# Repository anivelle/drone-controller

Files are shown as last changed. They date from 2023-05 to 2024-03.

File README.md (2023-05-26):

# PID Drone Controller

This is my repository for the drone controller I am building using the Arduino
Nano 33 BLE. This is an exercise for me in working directly with the Arduino's
hardware peripherals, as well as learning about PID (I have never taken a
feedback control course).

I'll be using some sort of time of flight (TOF) sensor to give the drone the
ability to hover at a certain height, along with a 9-axis IMU (currently the
BNO055 because I have it) to keep the drone stabilized in the air. That is all
that is currently planned, but if I enjoy this enough I might try autonomous
movement.

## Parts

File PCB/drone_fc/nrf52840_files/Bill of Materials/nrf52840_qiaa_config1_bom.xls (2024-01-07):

Bill of material
Device: | nRF52840-QIAA
Title: | Reference Layout Config. 1: VBUS supply, LDO only, USB
Version: | 1.3
Designator | Value | Description | Assembly | Footprint Doc
C1, C2, C17, C18 | 12pF | Capacitor, NP0, ±2% |  | 0402
C3 | 0.8pF | Capacitor, NP0, ±10% |  | 0402
C4 | 0.5pF | Capacitor, NP0, ±10% |  | 0402
C5, C7, C8, C12 | 100nF | Capacitor, X7R, ±10% |  | 0402
C6, C20 | 4.7µF | Capacitor, X7R, ±10% |  | 0603
C9 | 820pF | Capacitor, NP0, ±5% | Not required for Fxx and later | 0402
C10, C13, C22 | N.C. | Not mounted | Not mounted | 0402
C11 | 100pF | Capacitor, NP0, ±5% |  | 0402
C14, C15 | 1.0µF | Capacitor, X7R, ±10% |  | 0603
C19 | 4.7µF | Capacitor, X7S, ±10% |  | 0603
L1 | 4.7nH | High frequency chip inductor ±5% |  | 0402
R1 | 2R2 | Resistor, ±1%, 0.063W |  | 0402
U1 | nRF52840-QIAA | Multi-protocol Bluetooth Low Energy, IEEE 802.15.4, ANT and 2.4GHz proprietary system-on-chip |  | AQFN-73
X1 | 32MHz | XTAL SMD 2016, 32MHz, Cl=8pF, Total Tol: ±40ppm |  | XTAL_2016
X2 | 32.768kHz | XTAL SMD 3215, 32.768kHz, Cl=9pF, Total Tol: ±50ppm |  | XTAL_3215

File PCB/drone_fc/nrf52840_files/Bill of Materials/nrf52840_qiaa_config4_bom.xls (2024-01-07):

Bill of material
Device: | nRF52840-QIAA
Title: | Reference Layout Config. 4: VDDH supply, DCDC, USB
Version: | 1.3
Designator | Value | Description | Assembly | Footprint Doc
C1, C2, C17, C18 | 12pF | Capacitor, NP0, ±2% |  | 0402
C3 | 0.8pF | Capacitor, NP0, ±10% |  | 0402
C4 | 0.5pF | Capacitor, NP0, ±10% |  | 0402
C5, C7, C8, C12 | 100nF | Capacitor, X7R, ±10% |  | 0402
C6, C20 | 4.7µF | Capacitor, X7R, ±10% |  | 0603
C9 | 820pF | Capacitor, NP0, ±5% | Not required for Fxx and later | 0402
C10, C13, C22 | N.C. | Not mounted | Not mounted | 0402
C11 | 100pF | Capacitor, NP0, ±5% |  | 0402
C14, C15 | 1.0µF | Capacitor, X7R, ±10% |  | 0603
C16 | 47nF | Capacitor, X7R, ±10% |  | 0402
C19, C21 | 4.7µF | Capacitor, X7S, ±10% |  | 0603
L1 | 4.7nH | High frequency chip inductor ±5% |  | 0402
L2 | 10µH | Chip inductor, IDC,min = 50 mA, ±20% |  | 0603
L3 | 15nH | High frequency chip inductor ±10% |  | 0402
L4 | 10µH | Chip inductor, IDC,min = 80 mA, ±20% |  | 0603
U1 | nRF52840-QIAA | Multi-protocol Bluetooth Low Energy, IEEE 802.15.4, ANT and 2.4GHz proprietary system-on-chip |  | AQFN-73
X1 | 32MHz | XTAL SMD 2016, 32MHz, Cl=8pF, Total Tol: ±40ppm |  | XTAL_2016
X2 | 32.768kHz | XTAL SMD 3215, 32.768kHz, Cl=9pF, Total Tol: ±50ppm |  | XTAL_3215

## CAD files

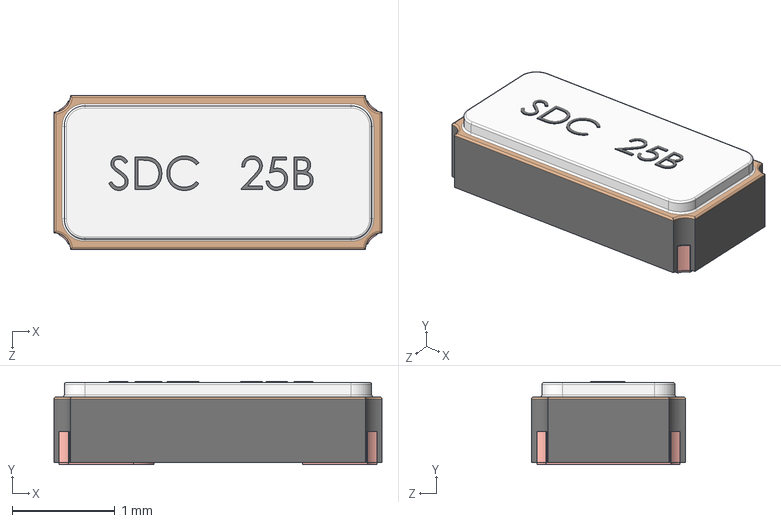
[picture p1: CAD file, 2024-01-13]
PCB/drone_fc/nrf52840_files/Altium Designer files/ALTIUM_EMBEDDED_MODELS/User Library-Siward_SX3215.step
3.20 x 0.81 x 1.50 mm

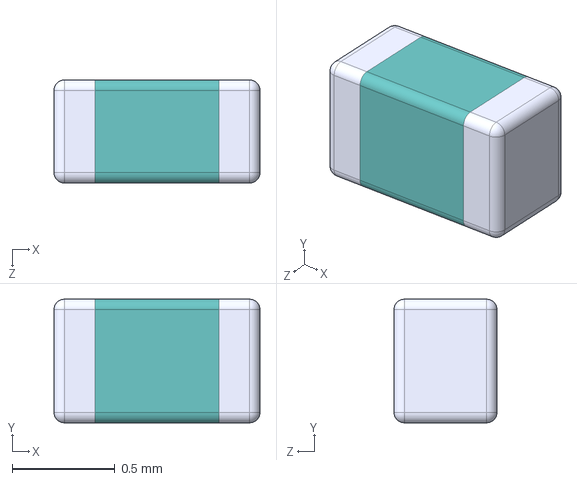
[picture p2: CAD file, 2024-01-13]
PCB/drone_fc/nrf52840_files/Altium Designer files/ALTIUM_EMBEDDED_MODELS/User Library-Chip Inductor 0402.step
1.00 x 0.6 x 0.5 mm

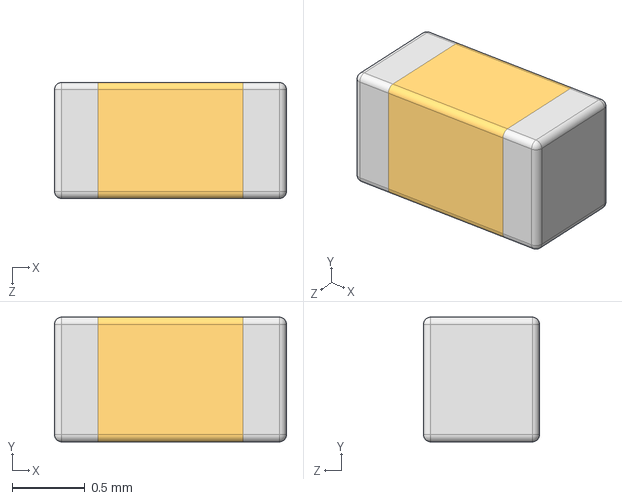
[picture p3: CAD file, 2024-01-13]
PCB/drone_fc/nrf52840_files/Altium Designer files/ALTIUM_EMBEDDED_MODELS/User Library-Chip Capacitor 0603.step
1.60 x 0.86 x 0.8 mm

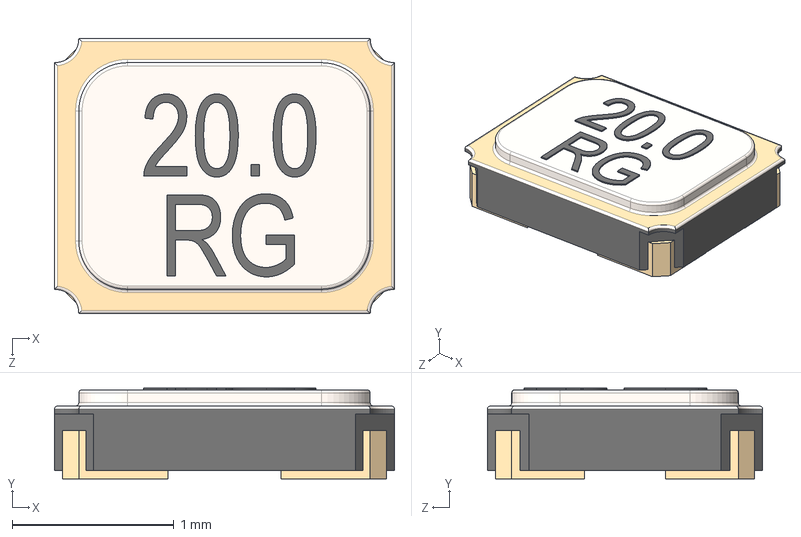
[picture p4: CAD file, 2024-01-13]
PCB/drone_fc/nrf52840_files/Altium Designer files/ALTIUM_EMBEDDED_MODELS/User Library-GeyerElectronics_KX5.step
2.10 x 0.56 x 1.70 mm

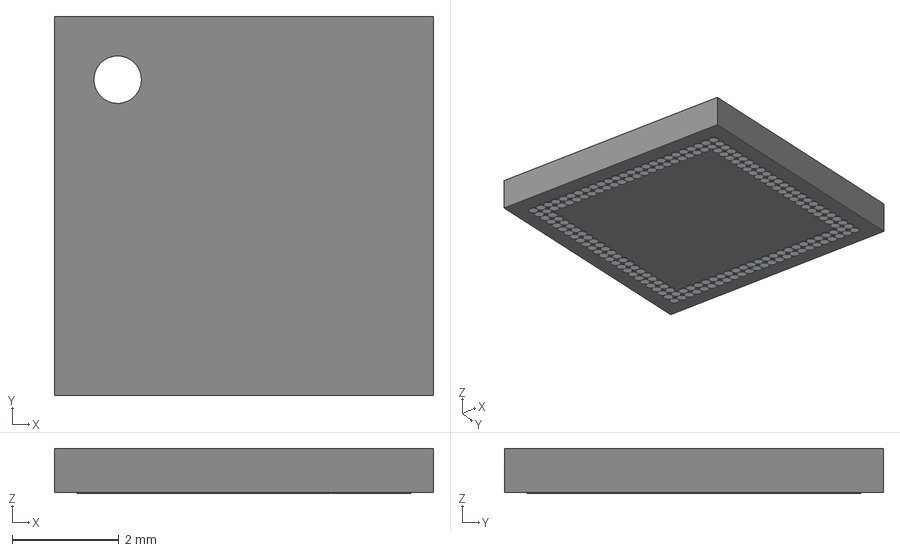
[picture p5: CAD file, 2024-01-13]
PCB/drone_fc/nrf52840_files/Altium Designer files/ALTIUM_EMBEDDED_MODELS/LGA88C25P25X25_700X700X85.step
7.10 x 7.10 x 0.85 mm
pinShape x 184

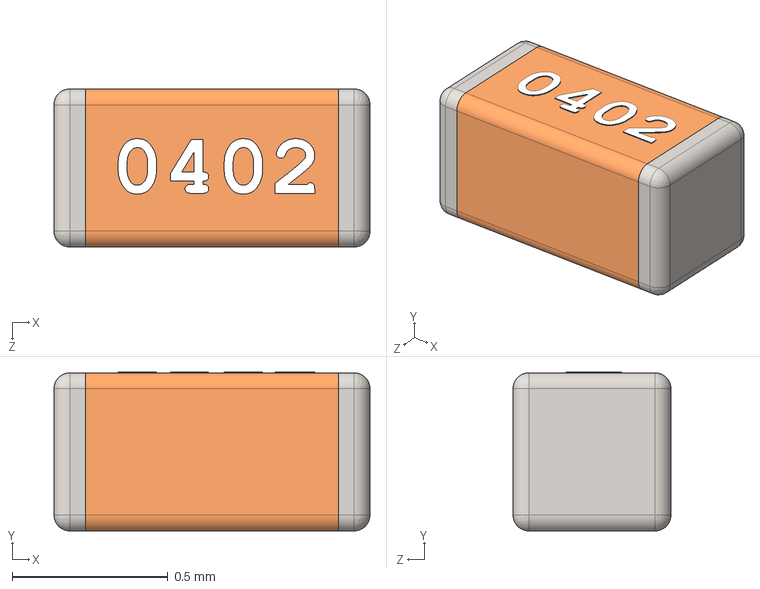
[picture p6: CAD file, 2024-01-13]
PCB/drone_fc/nrf52840_files/Altium Designer files/ALTIUM_EMBEDDED_MODELS/User Library-0402(1005M) Cap.step
1.02 x 0.511 x 0.508 mm

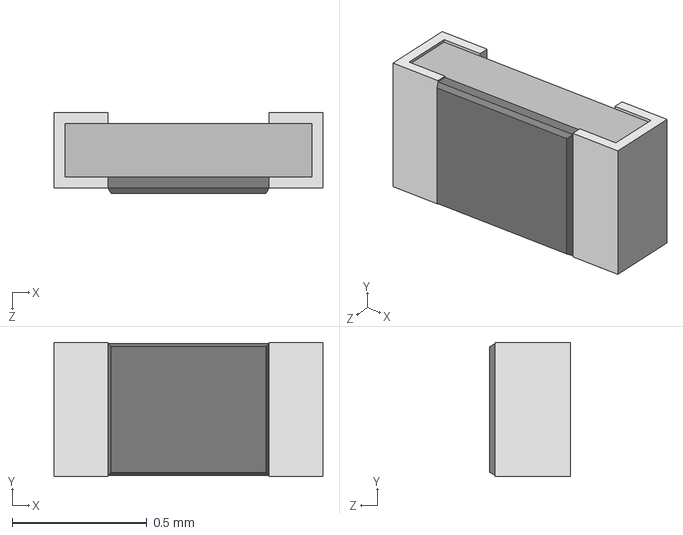
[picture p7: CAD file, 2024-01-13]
PCB/drone_fc/nrf52840_files/Altium Designer files/ALTIUM_EMBEDDED_MODELS/User Library-res0402-1.step
1.00 x 0.5 x 0.3 mm

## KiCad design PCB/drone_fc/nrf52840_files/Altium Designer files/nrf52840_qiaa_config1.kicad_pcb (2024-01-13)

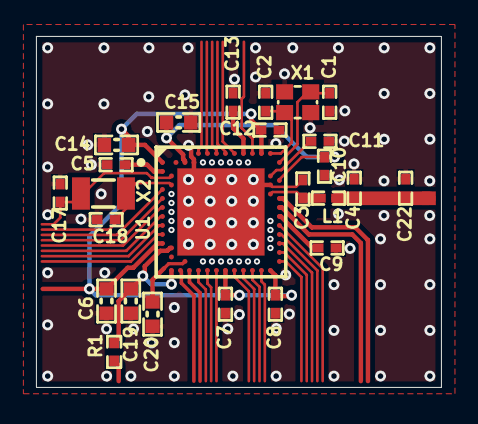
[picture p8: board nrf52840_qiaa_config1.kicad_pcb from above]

Board: 4 copper layers, 22.5 x 19.5 mm, 25 parts (0 on the bottom side), 15 nets.

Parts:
C1, C2: 12pF; CAPC1005X04L
C3: 0.8pF; CAPC1005X04L
C4: 0.5pF; _Applications_test_rsk_lib_RSK-ONLY_PcbLib_Passive.PcbLib_C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
C5, C7, C8: 100nF; CAPC1005X04L
C6, C19, C20: 4.7µF; _Applications_test_rsk_lib_RSK-ONLY_PcbLib_Passive.PcbLib_C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
C9: 820pF; CAPC1005X04L
C10, C13: N.C.; _Applications_test_rsk_lib_RSK-ONLY_PcbLib_Passive.PcbLib_C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
C11: 100pF; _Applications_test_rsk_lib_RSK-ONLY_PcbLib_Passive.PcbLib_C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
C12: 100nF; _Applications_test_rsk_lib_RSK-ONLY_PcbLib_Passive.PcbLib_C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
C14, C15: 1.0µF; _Applications_test_rsk_lib_RSK-ONLY_PcbLib_Passive.PcbLib_C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
C17, C18: 12pF; _Applications_test_rsk_lib_RSK-ONLY_PcbLib_Passive.PcbLib_C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
C22: N.C.; _Application_test_rsk_lib_RSK-ONLY_PcbLib_Passive.PcbLib_CA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
L1: 4.7nH; INDC1005X04L
R1: 2R2; _Applications_test_rsk_lib_RSK-ONLY_PcbLib_Passive.PcbLib_R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
U1: nRF52840-QIAA; _Applications_test_rsk_lib_RSK-ONLY_PcbLib_AQFN50P700X700X8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
X1: 32MHz; BT-XTAL_2016
X2: 32.768kHz; _Repositories_Applications_test_rsk_lib_RSK-ONLY_PcbLib_pcb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

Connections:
DEC1: C5.1, U1.C1
DEC3: C11.1, U1.D23
DEC4_6: C10.2, C15.2, U1.B5, U1.E24
GND: C1.2, C2.2, C3.1, C4.1, C5.2, C6.2, C7.2, C8.2, C9.2, C10.1, C11.2, C12.2, C13.2, C14.2, C15.1, C17.2, C18.2, C19.2, C20.2, C22.2, U1.74, U1.B7, U1.F23, X1.2, X1.4
NetC3_2: C3.2, L1.1, U1.H23
NetC9_1: C9.1, U1.N24
NetC13_1: C13.1, U1.A18
NetC20_1: C20.1, U1.AC5
P0.00/XL1: C17.1, U1.D2, X2.1
P0.01/XL2: C18.1, U1.F2, X2.2
RF: C4.2, C22.1, L1.2
VBUS_nRF: C19.1, R1.2, U1.AD2, U1.Y2
VDD_NRF: C6.1, C7.1, C8.1, C12.1, C14.1, U1.A22, U1.AD14, U1.AD23, U1.B1, U1.W1
XC1: C1.1, U1.B24, X1.1
XC2: C2.1, U1.A23, X1.3

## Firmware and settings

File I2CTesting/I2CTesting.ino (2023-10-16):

#include <stdint.h>
#include <stdio.h>
#include <Wire.h>
#include "BNO055.h"
#include "VL53L4CX.h"
#include "LowPowerTicker.h"

typedef enum State { CONFIGURING, CALIBRATING, FLYING } State_t;

BNO055 gyro(&Wire);
VL53L4CX distSensor(&Wire, A1);

int err;
int units;
uint8_t calibration;
State state;
State nextState;
uint8_t makeTransition = 0;
uint8_t calib_state = 0xFF;

mbed::LowPowerTicker ticker;

const char *titles[] = {"Heading", "Roll", "Pitch"};
volatile uint8_t drdy;
volatile uint8_t rrdy;
int angle[3];
volatile int temp;
uint8_t ready;
VL53L4CX_MultiRangingData_t ranging_data;
int status;

void timer_callback() {
    // if (NRF_TIMER3->EVENTS_COMPARE[0]) {
    drdy = 1;
    //   NRF_TIMER3->EVENTS_COMPARE[0] = 0;
    //   temp = NRF_TIMER3->EVENTS_COMPARE[0];
    //   temp;
    //}
}

void ready_callback() { rrdy = 1; }

void setup() {
    state = CONFIGURING;
    Serial.begin(115200);
    // Very important for serial to work properly (inside setup, at least)
    while (!Serial) {
    }
    Wire.begin();
    // Configuration stuff here
    delay(850); // Startup time for I2C? Not sure if necessary

    // Timer interrupt for the IMU (I still believe)
    // NRFX_IRQ_DISABLE(TIMER3_IRQn);
    // NRF_TIMER3->PRESCALER = PWM_PRESCALER_PRESCALER_DIV_32;
    // NRF_TIMER3->CC[0] = 5000;
    // NRF_TIMER3->BITMODE = TIMER_BITMODE_BITMODE_16Bit;
    // NRF_TIMER3->INTENSET |= TIMER_INTENSET_COMPARE0_Msk;
    // NRF_TIMER3->SHORTS = TIMER_SHORTS_COMPARE0_CLEAR_Msk;
    // NRFX_IRQ_PRIORITY_SET(TIMER3_IRQn, 7);
    // NRFX_IRQ_ENABLE(TIMER3_IRQn);
    drdy = 0;

    distSensor.begin();
    distSensor.VL53L4CX_Off();
    distSensor.InitSensor(0x12);
    attachInterrupt(A2, ready_callback, FALLING);
    status = distSensor.VL53L4CX_StartMeasurement();

    if (status) {
        Serial.println("Failed to init distSensor");
    }
    // Ends the config mode
    err = gyro.changeMode(NDOF);
    if (err != 0) {
        Serial.println("ERROR: Did not write properly");
        Serial.println(err);
    }
    err = gyro.readRegister(OPR_MODE);
    if (err != NDOF) {
        Serial.println("ERROR: Operation mode not set");
        Serial.println(err);
    } else {
        Serial.println("We're good");
    }

    ticker.attach(&timer_callback, 0.5f);
    units = gyro.readRegister(UNIT_SEL);
    Serial.println("Beginning Calibration");
    makeTransition = 1;
    nextState = CALIBRATING;
    // Serial.println(NRFX_IRQ_IS_ENABLED(TIMER3_IRQn));
}

void loop() {
    int numObjects;
    switch (state) {
    case CONFIGURING:
        break;
    case CALIBRATING:
        calibration = gyro.readRegister(CALIB_STAT);
        Serial.println(calibration, BIN);
        if ((calibration & calib_state) & (3 << 4)) {
            calib_state ^= (3 << 4);
            Serial.println("Gyro calibration done");
        }
        if ((calibration & calib_state) & (3 << 2)) {
            calib_state ^= (3 << 2);
            Serial.println("Accelerometer calibration done");
        }
        if ((calibration & calib_state) & 3) {
            calib_state ^= 3;
            Serial.println("Magnetometer calibration done");
        }
        if (calibration &
            (3 << 6) /*|| (~calib_state & 0b111111 == 0b111111)*/) {
            calib_state ^= (3 << 6);
            Serial.println("Done Calibrating");
            nextState = FLYING;
            makeTransition = true;
        }
        break;
    case FLYING:
        // status = distSensor.VL53L4CX_GetMeasurementDataReady(&ready);
      
        // Using this condition kinda invalidates the point of the hardware
        // interrupt (though frankly I'm only doing this to have a slower,
        // human-readable output). Thinking I might just use the hardware
        // interrupt as my entire data collection interrupt
        if (rrdy && drdy) {
            status = distSensor.VL53L4CX_GetMultiRangingData(&ranging_data);
            numObjects = ranging_data.NumberOfObjectsFound;
            Serial.print("Found ");
            Serial.print(numObjects);
            Serial.println(" Objects");
            for (int i = 0; i < numObjects; i++) {
                char buf[13];
                sprintf(buf, "Distance %d: ", i);
                Serial.print(buf);
                Serial.println(ranging_data.RangeData[i].RangeMilliMeter);
                Serial.println();
            }
            if (!status)
                distSensor.VL53L4CX_ClearInterruptAndStartMeasurement();
            for (int i = 0; i < 3; i++) {
                angle[i] = gyro.readEul((Axis)i);
                if (units & 4)
                    angle[i] /= 900;
                else
                    angle[i] /= 16;
                Serial.print(titles[i]);
                Serial.print(": ");
                Serial.println(angle[i]);
            }
            drdy = 0;
        }
        break;
    default:
        break;
    }
    if (makeTransition) {
        // Small things to do on exiting a state
        switch (state) {
        case CONFIGURING:
            if (nextState == FLYING)
                NRF_TIMER1->TASKS_START = 1;
            break;
        case CALIBRATING:
            NRF_TIMER1->TASKS_START = 1;
            NRF_TIMER1->TASKS_CLEAR = 1;
            break;
        case FLYING:
            NRF_TIMER1->TASKS_STOP = 1;
        }
        makeTransition = 0;
        state = nextState;
    }
}

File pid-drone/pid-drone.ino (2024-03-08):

#include <cstdio>
#include <stdint.h>
#include "mbed.h"
#include "VL53L4CX.h"
#include "PWM.h"
#include "DShot.h"
#include "Wire.h"
// Not using the BNO055 anymore
// #include "BNO055.h" 

#define TELEMETRY 0
#define POTENTIOMETER A0

uint16_t commands[4];
uint16_t throttle;

uint16_t seq[SEQ_SIZE];

VL53L4CX distanceSensor(&Wire, A1);
//BNO055 gyro(&Wire);

uint8_t dataReady;
int status;
uint16_t prevTime, curTime;

void setup() {
    // distanceSensor.VL53L4CX_WaitDeviceBooted();
    // distanceSensor.VL53L4CX_DataInit();
    Serial.begin(115200);
    // This causes the PWM output to wait until I open a serial monitor, 
    // which may or may not be desirable
    while (!Serial) {
        ;
    }
    Wire.begin();
    distanceSensor.begin();
    distanceSensor.VL53L4CX_Off();
    distanceSensor.InitSensor(0x12);

    distanceSensor.VL53L4CX_StartMeasurement();
    //gyro.writeRegister(OPR_MODE, AMG);
  
    commands[0] = 0;
    commands[1] = 0;
    commands[2] = 0;
    commands[3] = 0;
    CreateSequence(commands, seq);
    PWM_AddPins(0, P1_12);
    PWM_AddPins(1, P1_15);
    PWM_AddPins(2, P1_13);
    PWM_AddPins(3, P1_14);
    pinMode(POTENTIOMETER, INPUT);
    PWM_Init((uint32_t)&seq);
    
    Serial.println("Done initializing");
    prevTime = millis();
}

void loop() {
    curTime = micros();
    uint16_t command;
    if (counter > 10) {
        command = analogRead(POTENTIOMETER) * 2;
        if (command < 48)
            command = 48;
        for (int i = 0; i < 4; i++) {
            commands[i] = command;
        }
        // commands[0] = (commands[0] + 1) % 2048;
    }
    if (curTime - prevTime > 200) {
      CreateSequence(commands, seq);
      PWM_SendCommand((uint32_t)&seq); // Test this later to see if I have to update the address
      prevTime = curTime;
        if (counter < 255)
            counter++;
    }
  
    VL53L4CX_MultiRangingData_t rangeData;
    dataReady = 0;
    status = distanceSensor.VL53L4CX_GetMeasurementDataReady(&dataReady);
    if (!status && (dataReady != 0)) {
        distanceSensor.VL53L4CX_GetMultiRangingData(&rangeData);
        for (int i = 0; i < rangeData.NumberOfObjectsFound; i++) {
            char text[23];
            sprintf(text, "Found %1d: Distance %4d", i,
                    rangeData.RangeData[i].RangeMilliMeter);
            Serial.println(text);
        }
        Serial.println();
        // This is an important line (for some reason)!
        status = distanceSensor.VL53L4CX_ClearInterruptAndStartMeasurement();
    }
}

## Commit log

2023-05-26 Finally found the timer register macros after 3 hours. Off to a great start
2023-06-12 Realized I can just use one PWM module, but I do have to interweave the compare values into one sequence to be loaded from RAM, it's a little gross
2023-06-21 Okay now the sequence is in order and I know it is correct, need to check PWM output on an oscilloscope
    [pid-drone.ino]
2023-06-28 Made a 'simulation' of the drone in Unity. It's pretty bad but it does give me a visual representation of PID, which I appreciate. I think I may be calculating some of the terms wrong, as it doesn't 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
    [pid-drone.ino]
2023-07-08 This sensor is annoying :)
2023-07-09 Moved PWM and DShot stuff to separate header and source files for organization. Had the distance sensor working, but it seems enabling PWM on this board disables the loop. I thought maybe it was CPU 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
2023-07-09 Small line in pid-drone.ino and removed cache files from Git
2023-07-09 Note: XSHUT has to be connected to pin A1 (or another defined pin) when the sensor is turned on for it to not break everything
2023-07-11 Starting to build up I2C library to use within this project. Looks like the Nano 33 BLE's processor has an easy to use I2C/TWI peripheral so hopefully its a matter of reimplementing the functions in 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
2023-07-14 Well I have no idea if this I2C code works but I'd like to at least find out if the interrupt works. Can't make a volatile variable static to access it without a class object, though, and the compile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
    [pid-drone.ino]
2023-07-31 Moved around the libraries, decided I'm no longer making my own library for I2C, simply because the distance sensor (curse be upon it) is too dependent on Wire.h and I really don't feel like making t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
    [I2CTesting.ino, pid-drone.ino]
2023-08-05 Not even the beeps work, so either DShot is being generated wrong (odd, I had it working previously), or I am completely off base about something
    [pid-drone.ino]
2023-08-18 Well I forgot that the nRF52840 repeats its last duty cycle, so I thought maybe that would fix my motor issues, but no
    [pid-drone.ino]
2023-08-26 Temp commit to switch
2023-08-26 Beginnings of a gyro interface
2023-08-27 More gyroscope library
2023-09-04 The BNO055 library should be right, but nothing works!!! I realized I was using the wrong pins on the Arduino, but that didn't fix it
    [I2CTesting.ino]
2023-09-04 I had the address shifted and the pins wrong, and I forgot to try the address unshifted with the pins right. Writes but doesn't read now
    [I2CTesting.ino]
2023-09-04 I was using the register address as the requestFrom() address, rather than the BNO055's address. I fixed that error in the data retrieval functions but apparently forgot it in the readRegister() func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
    [I2CTesting.ino]
2023-09-05 It works! Updated function definitions to return int16_t, when I returned int the sign didn't read properly. Think I should probably also just update the readRegister() function to accept a length, t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
    [I2CTesting.ino]
2023-09-09 Added a small state machine, set up a calibration state and have the IMU printing absolute orientation. No hardware interrupt from the IMU, so I'm setting up a small timer interrupt on the Arduino. N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
2023-09-09 No idea why the interrupt won't work. Compare events also seem to happen irregularly, so I can't trust them. I can use the standard millis() and prevTime method I'm using now, but I don't like it
    [I2CTesting.ino]
2023-09-09 Well I've got it working with mbed API calls, but I don't like this method. I may take a look at the underlying code to see where I'm going wrong
    [I2CTesting.ino]
2023-09-10 Well I tried some more interrupt register stuff, and I think this is the best I'm getting. Still no clue why it doesn't work for me. May have to try on a clean project
    [I2CTesting.ino]
2023-09-16 Fixed DShot but the ESC has pull-ups on the motor wires and also the Arduino does not respond to resets
    [pid-drone.ino]
2023-10-16 Changed: Moved the VL53L4CX header bundle into a library so I could use it in all the sketches without having to copy it over and over. Also this could have been on a different branch but I did add t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
2023-12-18 Okay actually I'm reverting my code for now bringing the new changes in was a bad idea
    [pid-drone.ino]
2024-01-04 I rented an oscilloscope to find out I just needed to change the PWM output pin. This works. Now to test the output from the library
2024-01-07 Starting a PCB to replace a whole Nano, man is the chip complicated
    [LGA88C25P25X25_700X700X85.step, User Library-0402(1005M) Cap.step, User Library-Chip Capacitor 0603.step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]
2024-01-13 Starting a PCB with the nRF52840. The Nordic-provided boards crash KiCAD so I'm making it myself I guess
    [LGA88C25P25X25_700X700X85.step, User Library-0402(1005M) Cap.step, User Library-Chip Capacitor 0603.step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]
2024-01-16 DShot/PWM libraries have been fixed to actually work with every motor now
    [pid-drone.ino]
2024-02-21 Trying out both Zephyr and Mbed OS, currently looking like I may be able to use Zephyr with a user library to integrate the necessary Arduino functions (mostly Wire.h). I don't particularly want to u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
    [main.cpp, vl53lx_class.h]
2024-02-22 Brought in distance sensor code to test if Zephyr is actually capable of using it with the Arduino Core repository but haven't tested it yet. Luckily Zephyr also includes the nRF52840 register mappin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
2024-03-03 Configuration changes and an extra board overlay (both adapted from the Zephyr documentation) were necessary for serial communication to work. Distance sensor is spitting out garbage values though, w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
